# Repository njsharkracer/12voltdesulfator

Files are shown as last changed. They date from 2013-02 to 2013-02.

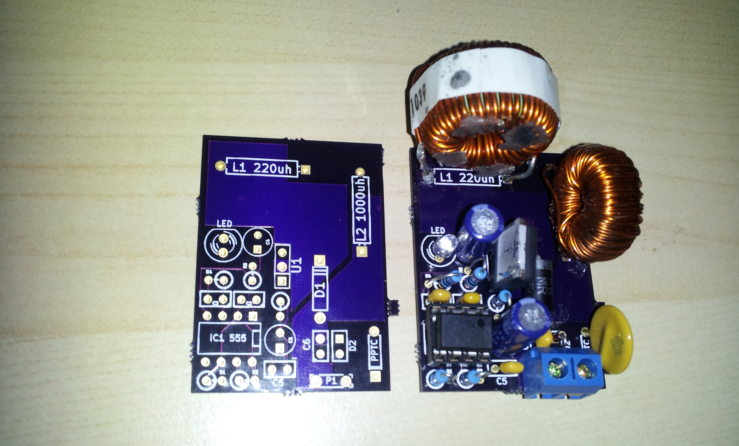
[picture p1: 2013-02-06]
pcb v0.90.jpg

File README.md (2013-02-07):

12 Volt DC Battery Desulfator Circuit (Gerber Files)

Thank you for checking out my repository for my version of a desulfator circuit.  It is a corrected version of "Frontier Springs" desulfator circuit.  In their version the mosfet was flipped making the circuit inoperative and I also added an led to show that the circuit was working.  

Feel free to download the latest version of the gerber files and make one for yourself.  I suggest using OSHPark.com to order your circuit boards.  These zip files are perfectly set up for OSHPark and they are the same one's I use.  

README.md - this file your reading  
parts_list.txt - parts list and part numbers.  
schematic vX.XX.jpg - Schematic picture  
desulfator vX.XX.zip - Gerber files suitable for uploading to OSHPark  
desulfator vX.XX kicad source.zip - source files and libraries for kicad EDA  
desulfator.pdf - Original desulfator article from "Home Power Magazine" issue #88  
pcb v0.90.jpg - Photo of unpopulated and populated PCB  

Lastly this is an open source hardware circuit.  I created the version you see here.  It if free for you to use.  If you feel inclined to give thanks to me, please throw me a few $$ with the button below.  All $ is used for my own prototyping of these circuits and every bit helps and is always appreciated!

[Pledgie][pledgie]
[pledgie]: http://www.pledgie.com/campaigns/19178

Also follow my other electronics projects on my YouTube channel:  www.youtube.com/njsharkracer

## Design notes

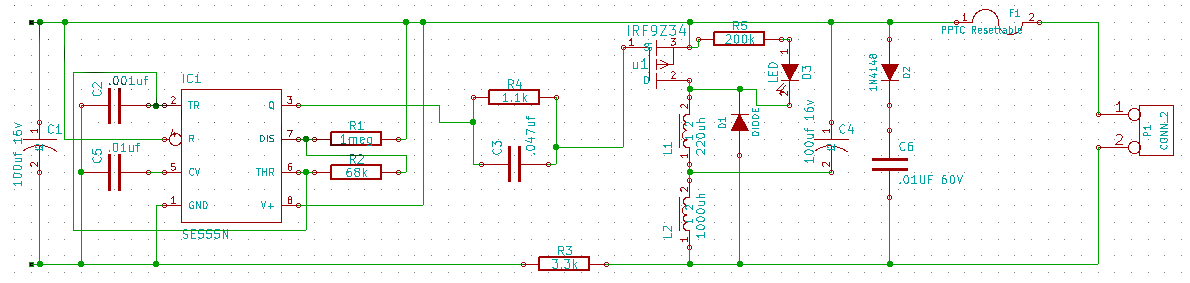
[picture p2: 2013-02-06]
schematic v0.91.jpg

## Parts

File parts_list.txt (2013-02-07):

Here is the parts list for my desulfator circuit.  I suggest using Newark.com to order your parts.  That's who I use.

1 - MULTICOMP - MCMF0W4FF1101A50 - RESISTOR, METAL FILM, 1.1KOHM, 250mW, 1%
1 - MULTICOMP - MCMF0W4FF3301A50 - RESISTOR, METAL FILM, 3.3KOHM, 250mW, 1%
1 - MULTICOMP - MCMF0W4FF6802A50 - RESISTOR, METAL FILM, 68KOHM, 250mW, 1%
1 - MULTICOMP - MCMF0W4FF1004A50 - RESISTOR, METAL FILM, 1MOHM, 250mW, 1% 
1 - MULTICOMP - MCMF0W4FF2003A50 - RESISTOR, METAL FILM, 200KOHM, 250mW, 1% 
1 - BOURNS JW MILLER - PM2110-102K-RC - POWER INDUCTOR, 1MH, 1.9A, 10% 
1 - BOURNS JW MILLER - PM2120-221K-RC - POWER INDUCTOR, 220UH, 5A, 10%
1 - TE CONNECTIVITY / RAYCHEM - RXEF110 - FUSE, PTC RESET, 72V, 1.1A, RADIAL
1 - ON SEMICONDUCTOR - MR856RLG - FAST RECOVERY DIODE, 3A, 600V AXIAL
1 - NTE ELECTRONICS - 1N4148 - SWITCHING DIODE, 100V, 300mA, DO-35 
2 - UNITED CHEMI-CON - ELXZ350ELL101MF15D - CAPACITOR ALUM ELEC 100UF, 35V, 20%, RADIAL
1 - MULTICOMP - MC0805N102J500A2.54MM - CAPACITOR CERAMIC 1000PF 50V, C0G, 5%, RAD
2 - MULTICOMP - MCMLR100V103KX7R - CAPACITOR CERAMIC 0.01UF, 100V, X7R, 10%, RAD
1 - MULTICOMP - MC0805B473K500A2.54MM - CAPACITOR CERAMIC 0.047UF, 50V, X7R, 10%, RAD
1 - INTERNATIONAL RECTIFIER - IRF9Z34NLPBF - P CHANNEL MOSFET, -55V, 19A, TO-262
1 - FCI - DILB8P-223TLF - DIP SOCKET, 8POS, 2.54MM, THROUGH HOLE
1 - TEXAS INSTRUMENTS - SA555PG4 - IC, TIMER, SINGLE, 16V, DIP-8
1 - CREE - C503C-WAN-CBADB151 - LED, COOL WHITE, 120MW, 46100MCD 
1 - MULTICOMP - MC24356 - TERMINAL BLOCK EUROSTYLE, 2POS, 26-12AWG

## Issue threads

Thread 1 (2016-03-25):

Inductor changed?

jassing, 2016-03-25:
Just checking on the inductor part #'s -- when I look up the part # listed, what comes up is a different looking inductor...

dalek1967, 2025-07-06:
I built a few of these a few years ago.  This is the info from my order.  I ordered from mouser but you can order them elsewhere if needed.

HCTI-220-5.8  Bel Signal Transformer 220UH 5.8Amps
2324-V-RC  Bourns  1.0mH

I know this is a old question but just in case you still need the info or someone else does.  I do wish this had mounting holes.  I'm trying to upgrade to a project that has mounting holes and is using KiCAD v9.

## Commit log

2013-02-06 version 0.90
    [desulfator-B_Cu.gbl, desulfator-B_Mask.gbs, desulfator-B_SilkS.gbo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]
2013-02-06 fixed resistor values
2013-02-06 fixed reversed R1 & R2, enlarged holes for 3A diode and inductors, missing silk screen for R3
2013-02-07 v0.91 source files for kicad
